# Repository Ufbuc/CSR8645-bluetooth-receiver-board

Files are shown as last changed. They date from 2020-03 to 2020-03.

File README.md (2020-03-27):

# CSR8645-bluetooth-receiver-board
Breakout board for F-3188 V2.0 bluetooth board with single ended output signal and onboard power supply.

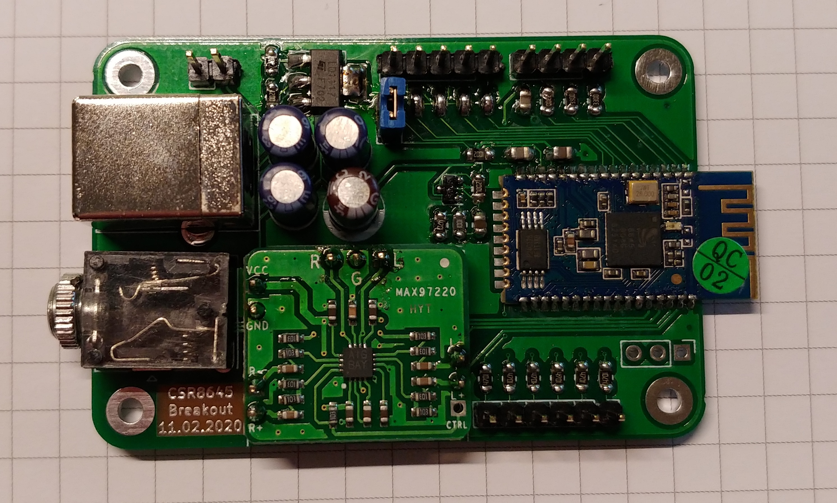
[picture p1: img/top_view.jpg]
Picture of assembled circuit board


This is a simple circuit board (43mm x 64mm) to make use of the features of the very common *F-3188 V2.0* which is based on the Qualcomm *CSR8645*. Simply connect power (5V via USB Type B or up to 15V via pin header) and 3.5mm phone connector to get an audio signal in aptX quality.

Pin headers can be used to connect status LEDs and control buttons. Many features can be customized by connecting a supported programmer.
A *MAX97220* board converts the differential ended signal from the *CSR8645* to a single ended signal. The onboard power supply uses a *LD1117 SC-R* to provide a stable input voltage (3.5-3.6V) for both mounted PCBs.

The output level is high enough to drive a dedicated amplifier. If the board is used to directly drive headphones it may be better to skip the onboard power supply and use 5V input voltage as input voltage for the *MAX97220*.

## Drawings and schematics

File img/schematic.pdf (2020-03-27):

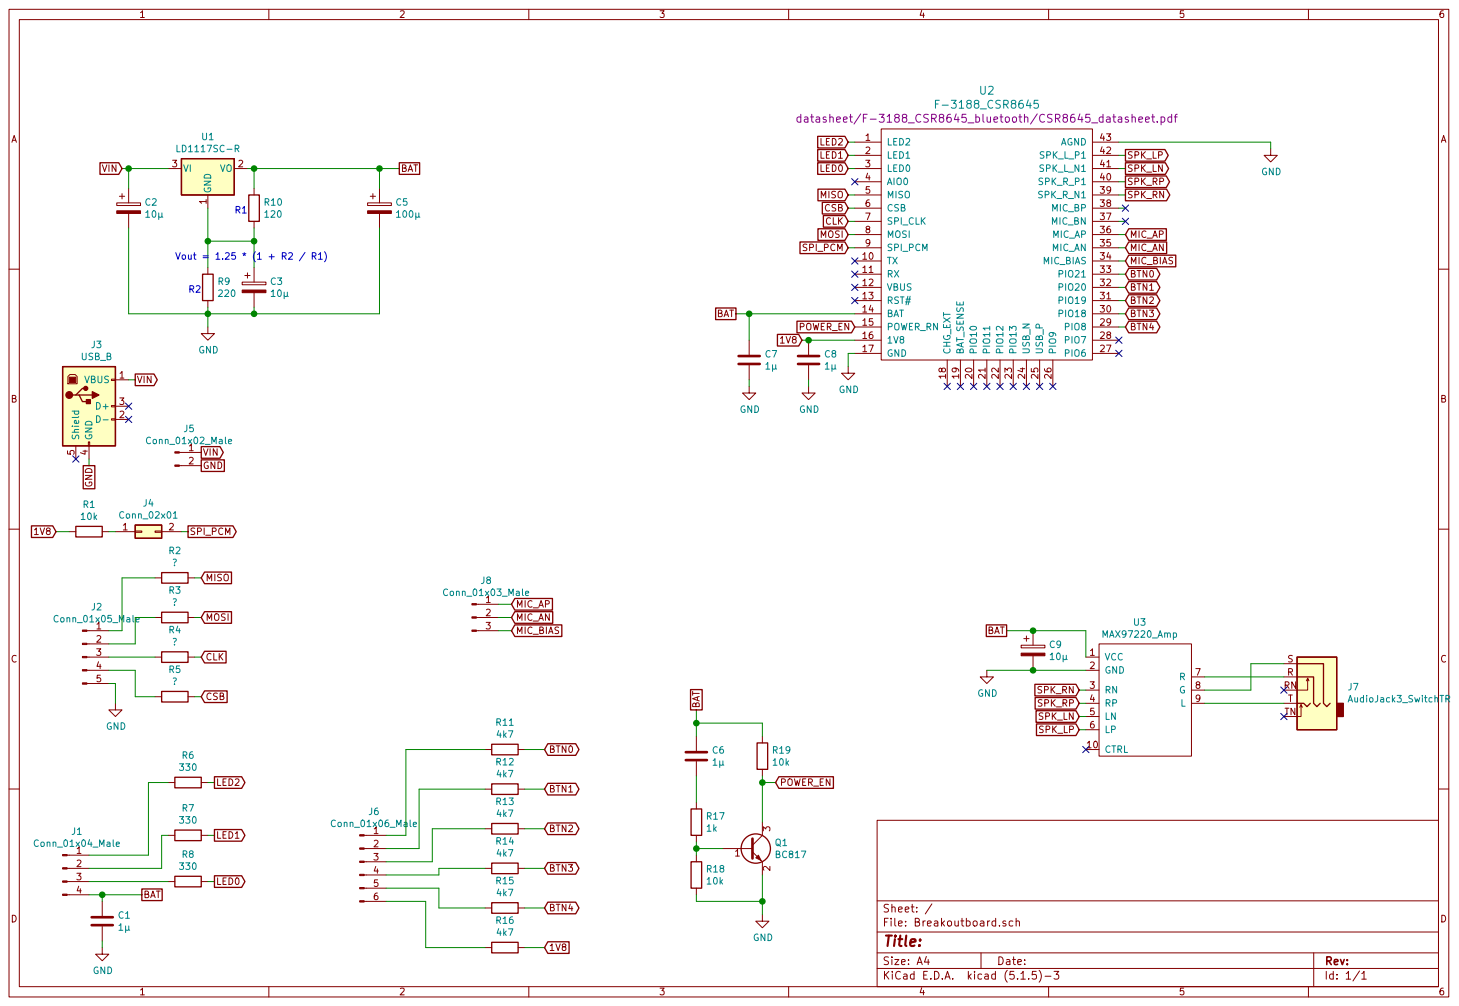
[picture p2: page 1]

1V8 MISO MOSI CSB CLK

Id: 1/1 Title: File: Breakoutboard.sch Sheet: / R16

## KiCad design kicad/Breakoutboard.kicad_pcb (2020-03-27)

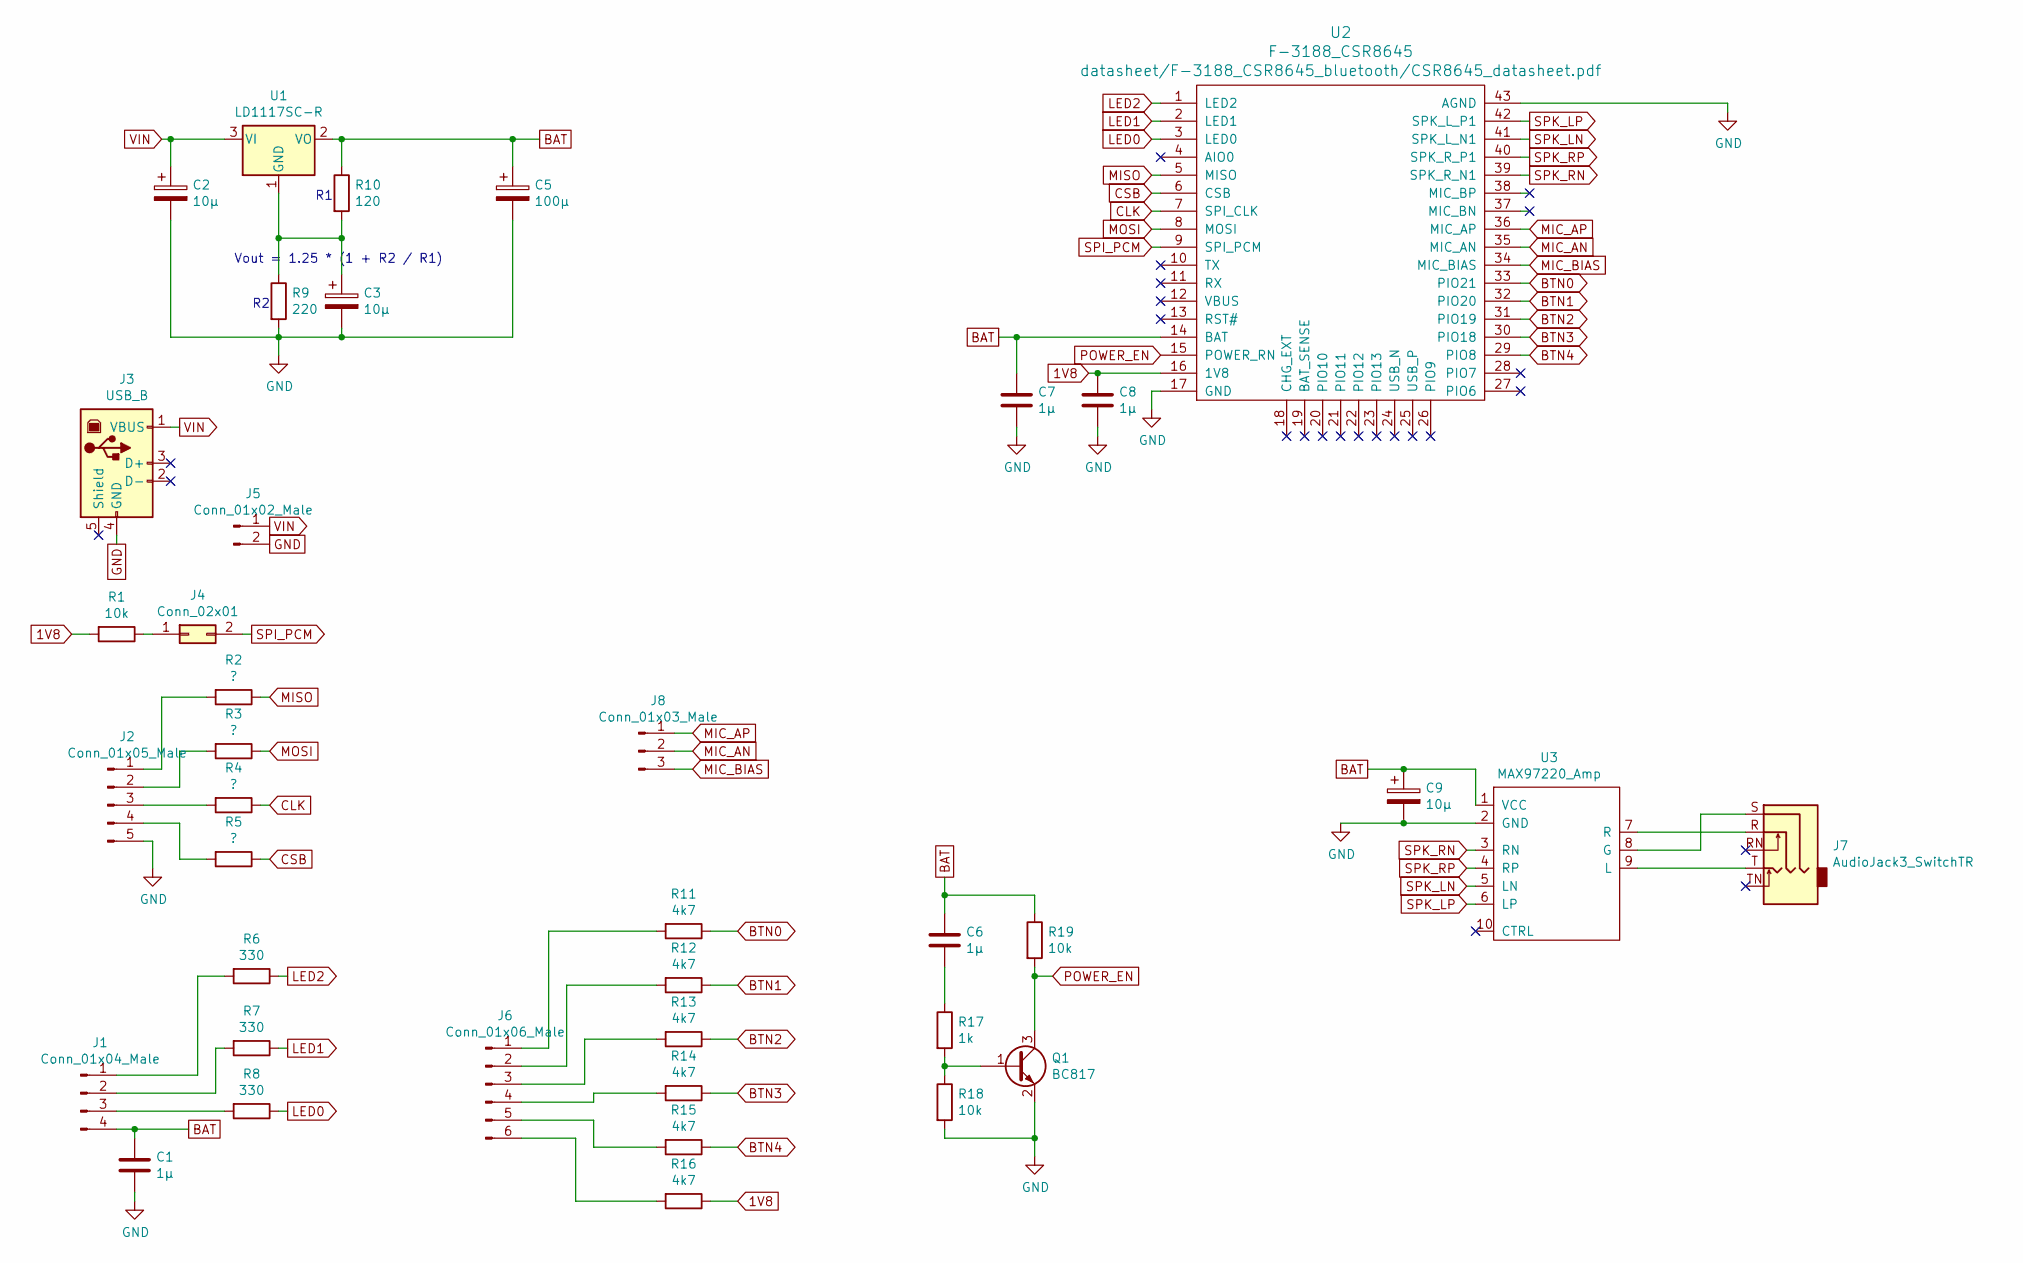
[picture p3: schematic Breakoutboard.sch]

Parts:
C1, C6, C7, C8: 1µ; C_0805_2012Metric_Pad1.15x1.40mm_HandSolder
C2, C3, C9: 10µ; CP_Radial_D5.0mm_P2.00mm
C5: 100µ; CP_Radial_D6.3mm_P2.50mm
J1: Conn_01x04_Male; PinHeader_1x04_P2.54mm_Vertical
J2: Conn_01x05_Male; PinHeader_1x05_P2.54mm_Vertical
J3: USB_B; USB_B_OST_USB-B1HSxx_Horizontal
J4: Conn_02x01; PinHeader_2x01_P2.54mm_Vertical
J5: Conn_01x02_Male; PinHeader_1x02_P2.54mm_Vertical
J6: Conn_01x06_Male; PinHeader_1x06_P2.54mm_Vertical
J7: AudioJack3_SwitchTR; Jack_3.5mm_Ledino_KB3SPRS_Horizontal
J8: Conn_01x03_Male; PinHeader_1x03_P2.54mm_Vertical
Q1: BC817; SOT-23
R1, R18, R19: 10k; R_0805_2012Metric_Pad1.15x1.40mm_HandSolder
R2, R3, R4, R5: ?; R_0805_2012Metric_Pad1.15x1.40mm_HandSolder
R6, R7, R8: 330; R_0805_2012Metric_Pad1.15x1.40mm_HandSolder
R9: 220; R_0805_2012Metric_Pad1.15x1.40mm_HandSolder
R10: 120; R_0805_2012Metric_Pad1.15x1.40mm_HandSolder
R11, R12, R13, R14, R15, R16: 4k7; R_0805_2012Metric_Pad1.15x1.40mm_HandSolder
R17: 1k; R_0805_2012Metric_Pad1.15x1.40mm_HandSolder
U1: LD1117SC-R; SOT-223-3_TabPin2
U2: F-3188_CSR8645
U3: MAX97220_Amp; MAX97220_amp

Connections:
1V8: C8.1, R1.2, R16.1, U2.16 (1V8)
BAT: C1.1, C5.1, C6.1, C7.1, C9.1, J1.4, R10.1, R19.1, U1.2 (VO), U2.14 (BAT), U3.1 (VCC)
BTN0: R11.1, U2.33 (PIO21)
BTN1: R12.1, U2.32 (PIO20)
BTN2: R13.1, U2.31 (PIO19)
BTN3: R14.1, U2.30 (PIO18)
BTN4: R15.1, U2.29 (PIO8)
CLK: R4.1, U2.7 (SPI_CLK)
CSB: R5.1, U2.6 (CSB)
GND: C1.2, C2.2, C3.2, C5.2, C7.2, C8.2, C9.2, J2.5, J3.4 (GND), J5.2, Q1.2 (E), R9.2, R18.2, U2.17 (GND), U2.43 (AGND), U3.2 (GND)
LED0: R8.1, U2.3 (LED0)
LED1: R7.1, U2.2 (LED1)
LED2: R6.1, U2.1 (LED2)
MIC_AN: J8.2, U2.35 (MIC_AN)
MIC_AP: J8.1, U2.36 (MIC_AP)
MIC_BIAS: J8.3, U2.34 (MIC_BIAS)
MISO: R2.1, U2.5 (MISO)
MOSI: R3.1, U2.8 (MOSI)
unnamed: C3.1, R9.1, R10.2, U1.1 (GND)
unnamed: C6.2, R17.1
unnamed: J1.1, R6.2
unnamed: J1.2, R7.2
unnamed: J1.3, R8.2
unnamed: J2.1, R2.2
unnamed: J2.2, R3.2
unnamed: J2.3, R4.2
unnamed: J2.4, R5.2
unnamed: J4.1, R1.1
unnamed: J6.1, R11.2
unnamed: J6.2, R12.2
unnamed: J6.3, R13.2
unnamed: J6.4, R14.2
unnamed: J6.5, R15.2
unnamed: J6.6, R16.2
unnamed: J7.R, U3.7 (R)
unnamed: J7.S, U3.8 (G)
unnamed: J7.T, U3.9 (L)
unnamed: Q1.1 (B), R17.2, R18.1
PIO12: U2.22 (PIO12)
PIO13: U2.23 (PIO13)
POWER_EN: Q1.3 (C), R19.2, U2.15 (POWER_RN)
SPI_PCM: J4.2, U2.9 (SPI_PCM)
SPK_LN: U2.41 (SPK_L_N1), U3.5 (LN)
SPK_LP: U2.42 (SPK_L_P1), U3.6 (LP)
SPK_RN: U2.39 (SPK_R_N1), U3.3 (RN)
SPK_RP: U2.40 (SPK_R_P1), U3.4 (RP)
VIN: C2.1, J3.1 (VBUS), J5.1, U1.3 (VI)

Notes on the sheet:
Vout = 1.25 * (1 + R2 / R1)

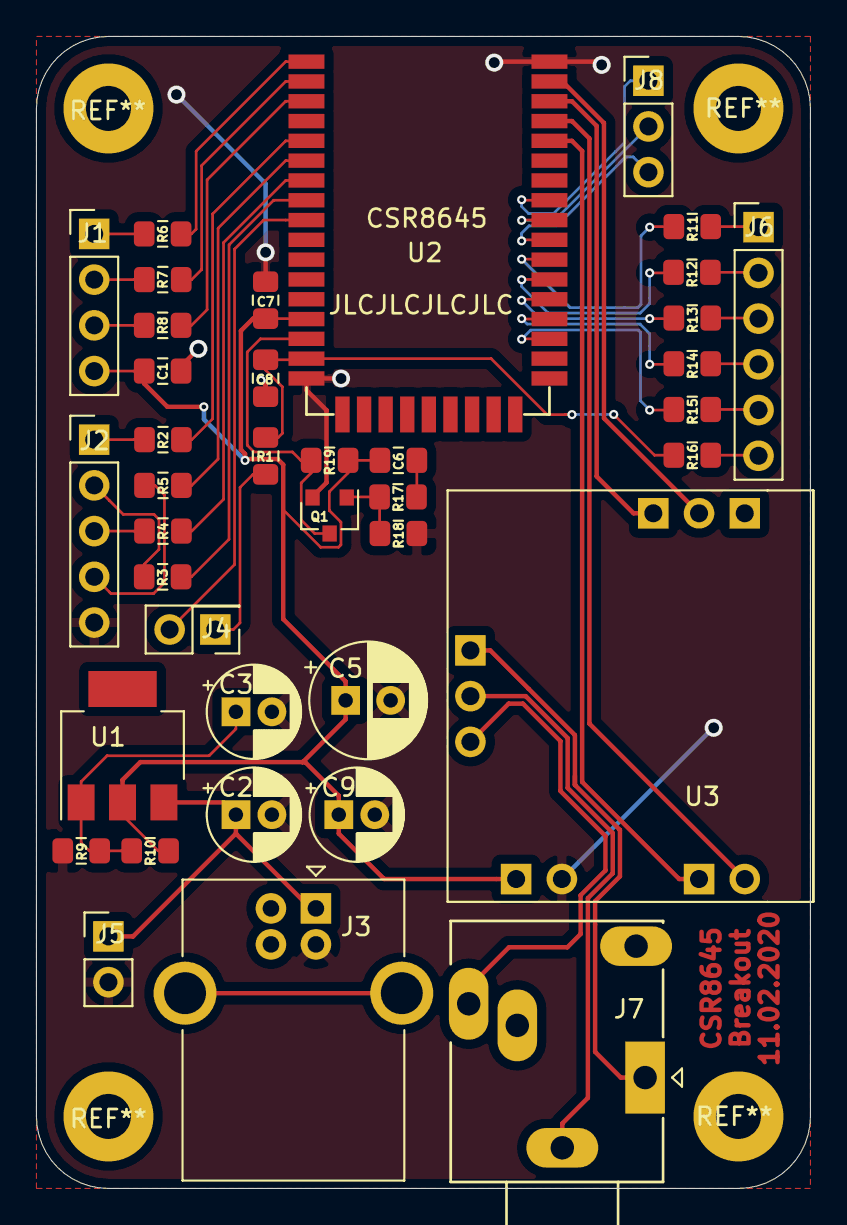
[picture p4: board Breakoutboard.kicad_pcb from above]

Board: 2 copper layers, 43.0 x 64.0 mm, 39 parts (0 on the bottom side), 45 nets.
